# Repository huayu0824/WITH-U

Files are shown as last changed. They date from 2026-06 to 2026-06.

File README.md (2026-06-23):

<p align="center">
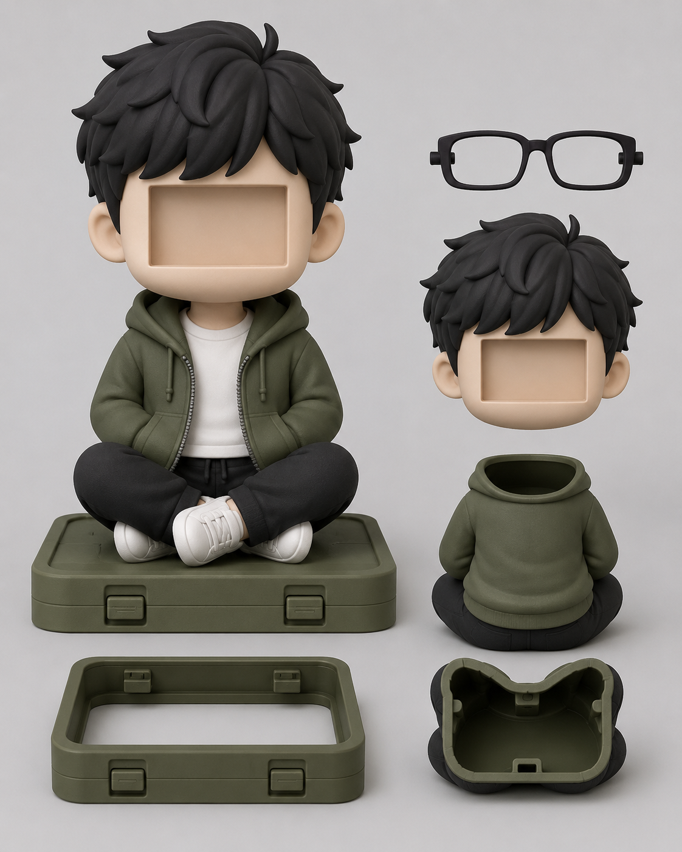
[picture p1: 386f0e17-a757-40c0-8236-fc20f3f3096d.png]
WITH-U
  
  <em>第一版，一言难尽...</em>
  resized-611846921-b86d6b1a-e5b0-4598-bc16-5bbaf18762d4
  <em>第三版</em>

</p>

<h1 align="center">WITH-U 🤖🧸</h1>

<p align="center">
  <em>我把另一个自己写进了代码里，装进玩偶，让它替我去陪她。</em>
</p>

<p align="center">
  
  
  
  
  
</p>

---

**WITH-U** 是一个实体 AI 语音交互玩偶项目。基于 ESP32-S3 构建硬件本体，端到端跑通语音识别→大模型推理→超拟声合成，装进 3D 打印外壳里，让ta变成一个可以抱在怀里说话的存在。

## ✨ 功能一览

| 功能 | 说明 |
|---|---|
| 🎤 **语音对话** | 按住说话，松开自动回复。端到端延迟约 2~4 秒 |
| 🗣️ **超拟声 TTS** | CosyVoice 复刻声音，不是机器人腔 |
| 🖥️ **OLED 显示** | 实时反馈对话状态：听、想、说 |
| 🔄 **OTA 升级** | 远程推送固件，不用拆外壳 |
| 📊 **Web 管理面板** | 日志监控、手动推送语录、系统控制 |
| 💾 **对话记录** | 每条对话自动存到 TF 卡 |
| 🐚 **3D 打印外壳** | 自锁按钮、USB-C 充电、完整外观设计 |

## 📐 架构

```
┌─────────────────────────┐         ┌──────────────────────────────┐
│    ESP32-S3 硬件本体      │         │        FastAPI 后端            │
│                          │         │                              │
│  ┌───────────────────┐   │ HTTP/WS │  ┌────────────────────┐     │
│  │ INMP441 麦克风     │──┼─────────┼──┤ ASR 语音识别       │     │
│  │ MAX98357 扬声器    │──┼─────────┼──┤ → DeepSeek LLM     │     │
│  │ 0.96" OLED        │   │         │  │ → CosyVoice TTS   │     │
│  │ SHT3X 温湿度      │   │         │  └────────────────────┘     │
│  │ TF 卡存储          │   │         │                              │
│  └───────────────────┘   │         │  阿里云 · DeepSeek · DashScope│
│  ┌───────────────────┐   │         └──────────────────────────────┘
│  │ WiFi + OTA 升级    │   │
│  │ Web 管理面板(HTML) │   │
│  └───────────────────┘   │
└─────────────────────────┘
```

## 🧰 硬件清单

| 组件 | 型号 | 用途 |
|---|---|---|
| **主控** | ESP32-S3 (16MB Flash + 8MB PSRAM) | 大脑，跑 WiFi + 音频处理 |
| **麦克风** | INMP441 (I2S MEMS) | 拾音 |
| **功放** | MAX98357A (I2S 3W) | 驱动扬声器 |
| **扬声器** | 3W 4Ω | 发声 |
| **显示屏** | 0.96" OLED (SSD1306, I2C) | 状态反馈 |
| **温湿度** | SHT3X (I2C) | 环境感知 |
| **存储** | TF 卡 (SPI 模式) | 对话记录、音频缓存 |
| **电源** | 3.7V 锂电池 + USB-C 充电 | 便携供电 |

## 📁 项目结构

```
WITH-U/
├── esp32_voice_assistant/        # ESP32-S3 固件 (Arduino/PlatformIO)
│   ├── esp32_voice_assistant.ino  # 主程序
│   ├── config.h                   # 硬件配置
│   ├── oled_display.h             # OLED 驱动
│   ├── sd_card.h                  # TF 卡读写
│   ├── sensors.h                  # 温湿度传感器
│   ├── ota_update.h               # OTA 远程升级
│   ├── server/                    # 板载 Web 服务 + 管理面板
│   ├── gerber_output/             # PCB Gerber 文件
│   └── tools/                     # 音频处理工具
├── my-ai-backend/                # AI 后端服务 (FastAPI)
│   ├── main.py                    # API 入口
│   ├── stt.py                     # 阿里云语音识别
│   ├── llm.py                     # DeepSeek 对话
│   ├── tts.py                     # CosyVoice 语音合成
│   └── config.example.py          # 密钥配置模板
├── 386f0e17-a757-40c0-8236-fc20f3f3096d.png  # 项目封面
├── README.md
└── LICENSE
```

## 🚀 快速开始

### 前置条件

- Python 3.10+
- PlatformIO (VS Code 插件或 CLI)
- ESP32-S3 开发板 + INMP441 + MAX98357A
- 阿里云 / DeepSeek / DashScope API 密钥

### 1️⃣ 后端部署

```bash
cd my-ai-backend
pip install -r requirements.txt

# 配置密钥
cp config.example.py .env
# 编辑 .env，填入你的阿里云、DeepSeek、DashScope 密钥

python main.py
```

后端默认运行在 `http://localhost:8000`。

### 2️⃣ 固件烧录

用 VS Code 打开 `esp32_voice_assistant/`，PlatformIO 会自动识别：

```bash
cd esp32_voice_assistant
pio run -t upload
```

或者直接串口烧录编译好的固件。

### 3️⃣ 硬件接线

参考 `config.h` 中的引脚定义：

| 外设 | 引脚 |
|---|---|
| INMP441 麦克风 | BCLK=5, WS=4, DIN=6 |
| MAX98357A 扬声器 | BCLK=15, WS=16, DOUT=7 |
| 按钮 | IO0 (GND 触发) |
| OLED (I2C) | SDA=41, SCL=42 |
| SHT3X (I2C) | 0x44 |
| TF 卡 (SPI) | CS=10, MOSI=11, SCK=12, MISO=13 |

### 4️⃣ 连接玩偶

按住按钮说话，松开后自动发送到后端 → AI 回复 → 扬声器播放。

## 💡 项目起源

> 重庆到山东，一千多公里。
> 见不到面的时候，就让另一个我去陪她。
> **小小倪**是另一个我，替我在她身边说一声 "我在"。

项目名 **WITH-U** —— 和你在一起。

## 📄 License

[MIT](LICENSE) — 随意使用，保留出处即可。

---

<p align="center">
  <a href="https://github.com/huayu0824/WITH-U/issues">反馈问题</a> ·
  <a href="https://github.com/huayu0824/WITH-U/discussions">讨论交流</a>
</p>

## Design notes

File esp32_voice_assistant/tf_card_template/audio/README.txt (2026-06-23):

PCM 文件格式：16000Hz、16-bit、有符号小端、单声道、无 WAV 头。

wake.pcm                 唤醒提示音
shutdown.pcm             休眠提示音
commands/time.pcm        时间固定指令
commands/test.pcm        本地播放测试

可使用 tools/prepare_audio.py 将 PCM WAV 转换为裸 PCM。

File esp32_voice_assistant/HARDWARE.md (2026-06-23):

# ESP32-S3-WROOM-1 玩偶硬件接入

## 引脚分配

| 功能 | 模块引脚 | ESP32-S3 GPIO | 供电 |
|---|---|---:|---|
| INMP441 | SCK / WS / SD | 5 / 4 / 6 | 3.3V |
| MAX98357A | BCLK / LRC / DIN | 15 / 16 / 7 | 5V |
| 说话按钮 | 一端 / 另一端 | GPIO0 / GND | 内部上拉 |
| TF 卡 SPI | CS / MOSI / SCK / MISO | 10 / 11 / 12 / 13 | 3.3V |
| SHT3X | SDA / SCL | 41 / 42 | 3.3V |
| 电池采样 | 100k/100k 分压中点 | GPIO1 | 最大输入约 2.1V |

所有模块必须共地。MAX98357A 的 GND 和电源回路应短而粗，避免再次出现功放参考地抖动。

## TF 卡

- 使用 FAT32。
- 推荐原生 3.3V TF 模块，不推荐带 AMS1117、面向 5V Arduino 的慢速模块。
- 面包板不稳定时将 SPI 频率从 20MHz 降到 10MHz，并缩短四根信号线。
- 卡根目录结构参考 `tf_card_template/`。

## 锂电池与充电

推荐结构：

```text
带保护 3.7V 锂电池
  -> 支持 power-path/load-sharing 的充电模块
  -> 稳压 5V
  -> ESP32 开发板 5V/VIN + MAX98357A VIN
```

可选模块方向：BQ24074 类电源路径充电板，或带充电、保护、5V 升压和负载管理的完整电源模块。

若使用 TP4056：

```text
电池 -> TP4056(B+/B-)
TP4056(OUT+/OUT-) -> 5V 升压模块 -> ESP32 5V/VIN
```

TP4056 本身没有可靠的边充边用电源路径。充电时持续运行负载可能导致充电终止判断失效，因此成品玩偶不建议只靠 TP4056 实现边充边玩。

禁止事项：

- 不要把满电 4.2V 锂电池直接接 ESP32 的 3.3V 引脚。
- 不要把电池直接接 MAX98357A 后再把同一路当作稳定 3.3V 使用。
- 不要省略电池保护、短路保护和总电源开关。

## 去耦建议

- MAX98357A VIN 附近：220uF 电解 + 0.1uF 陶瓷。
- ESP32 5V 输入附近：100uF 电解。
- TF 卡 3.3V 附近：47uF + 0.1uF。
- 最终成品使用焊接洞洞板或 PCB，不保留长面包板跳线。

## 软件开关

在 `config.h` 中，模块实际接好后再启用：

```cpp
#define ENABLE_VAD              1
#define ENABLE_AUTO_SLEEP       1
#define ENABLE_SHT3X            1
#define ENABLE_BATTERY_MONITOR  1
```

首次启用 VAD 时观察串口 RMS，安静环境阈值应高于底噪、低于正常说话幅度。

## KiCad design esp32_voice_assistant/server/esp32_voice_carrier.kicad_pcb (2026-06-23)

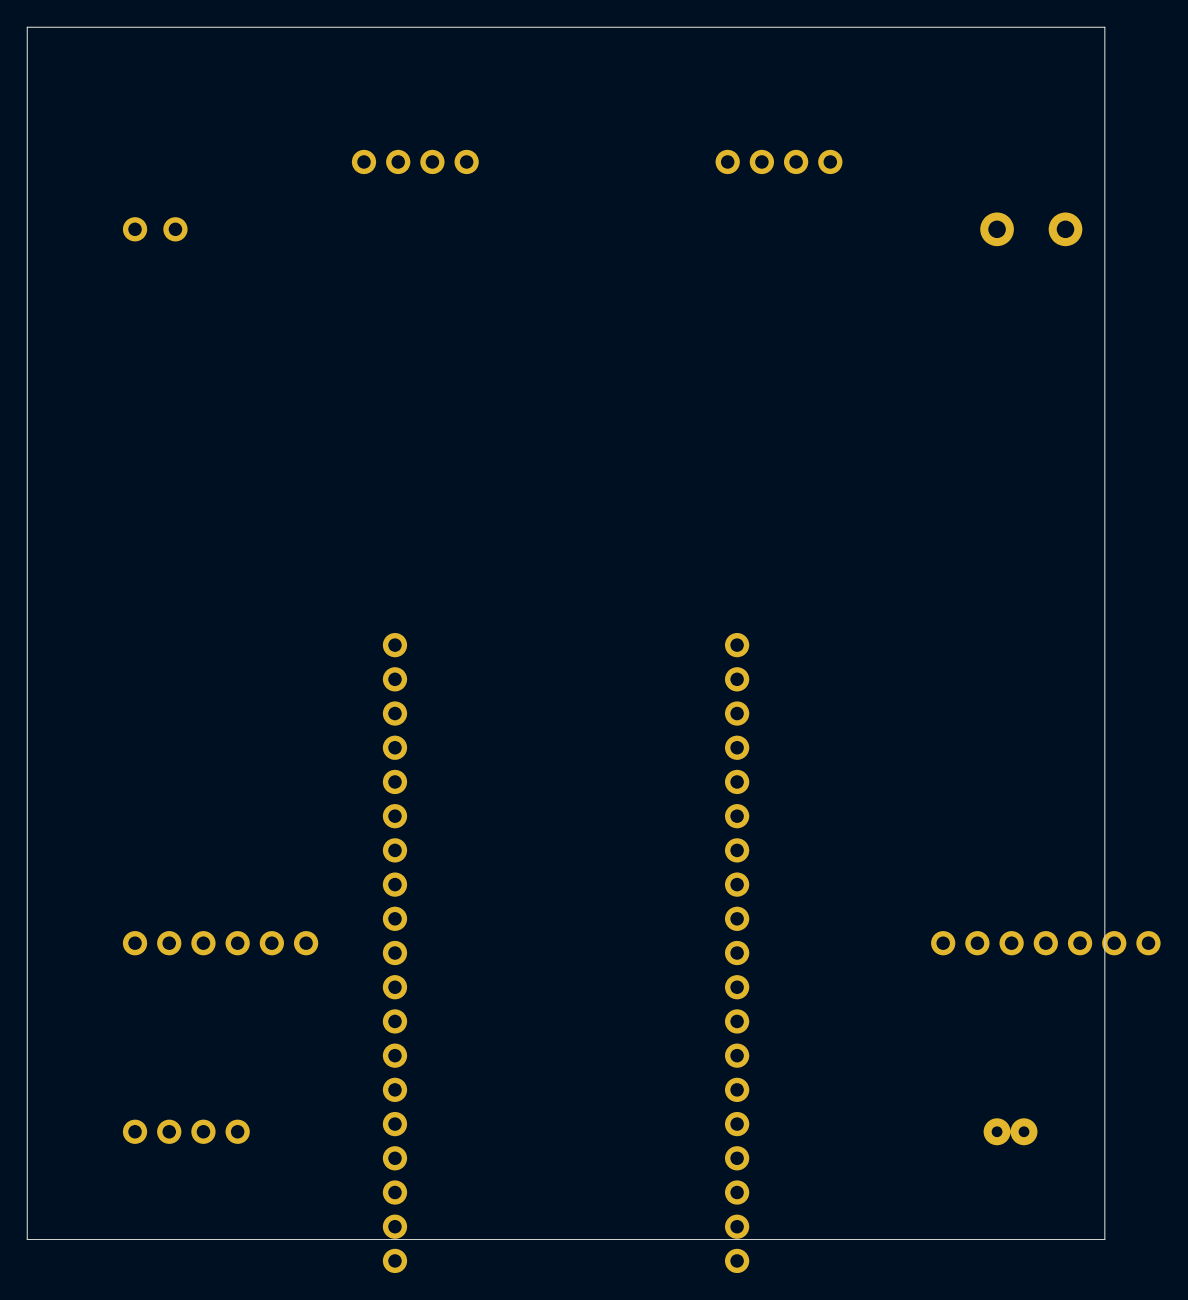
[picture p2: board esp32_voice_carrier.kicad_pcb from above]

Board: 2 copper layers, 80.0 x 90.0 mm, 9 parts (0 on the bottom side), 11 nets, no tracks yet.

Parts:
BAT1: BATTERY; JST_PH_B2B-PH-K_1x02_P2.0mm_Vertical
J_CHG: CHARGER; PinHeader_1x4_P2.54mm_Vertical
J_ESP32: ESP32-S3; PinSocket_2x19_P2.54mm_Vertical
J_MIC: INMP441; PinHeader_1x6_P2.54mm_Vertical
J_OLED: OLED; PinHeader_1x4_P2.54mm_Vertical
J_SHT3X: SHT3X; PinHeader_1x4_P2.54mm_Vertical
J_SPK: MAX98357; PinHeader_1x7_P2.54mm_Vertical
SPK1: SPEAKER; TerminalBlock_bornier-2_P5.08mm
SW1: BTN; SW_SPST_TL3342

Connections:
3V3: J_ESP32.1A, J_ESP32.19B, J_MIC.1, J_OLED.1, J_SHT3X.1
5V: BAT1.1, J_CHG.3, J_ESP32.2B, J_ESP32.17A, J_SPK.1, J_SPK.7
GND: BAT1.2, J_CHG.2, J_CHG.4, J_ESP32.1B, J_ESP32.4A, J_ESP32.18A, J_MIC.2, J_MIC.6, J_OLED.2, J_SHT3X.2, J_SPK.2, J_SPK.6, SPK1.2, SW1.2
I2C_SCL: J_ESP32.3A, J_OLED.4, J_SHT3X.4
I2C_SDA: J_ESP32.2A, J_OLED.3, J_SHT3X.3
MIC_BCLK: J_ESP32.9A, J_MIC.4
MIC_DIN: J_ESP32.11A, J_MIC.3
MIC_WS: J_ESP32.10A, J_MIC.5
SPK_BCLK: J_ESP32.12A, J_SPK.5
SPK_DOUT: J_ESP32.16A, J_SPK.3
SPK_WS: J_ESP32.15A, J_SPK.4

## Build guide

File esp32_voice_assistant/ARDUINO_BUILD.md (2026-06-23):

# Arduino IDE 编译设置

开发板：ESP32-S3-WROOM-1 N16R8（16MB Flash、8MB Octal PSRAM）。

推荐设置：

| 选项 | 值 |
|---|---|
| Board | ESP32S3 Dev Module |
| USB CDC On Boot | Enabled |
| CPU Frequency | 240MHz |
| Flash Size | 16MB |
| Flash Mode | QIO 80MHz |
| Partition Scheme | 16MB Flash 对应分区 |
| PSRAM | OPI PSRAM |
| Upload Speed | 921600；不稳定时改 460800 |

库管理器依赖：

- ArduinoJson，作者 Benoit Blanchon
- WebSockets，作者 Markus Sattler / Links2004
- WiFiManager，作者 tzapu
- ESP8266Audio，作者 Earle F. Philhower

烧录后的关键启动日志：

```text
[MEM] 缓冲区位于 PSRAM
[MEM] 录音缓冲区: 1924096 bytes
[SD] 未检测到 TF 卡
[CHAR] 使用内置默认角色（无TF卡）
[OK] INMP441
[WS] connected
```

若出现 `PSRAM 不可用，回退 DRAM`，先检查 Tools -> PSRAM 是否选择 `OPI PSRAM`。

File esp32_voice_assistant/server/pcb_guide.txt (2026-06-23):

============================================
ESP32-S3 玩偶底板 - 部件位置及接线说明
============================================
板尺寸: 80mm × 90mm
层数: 2层 (双面板)

=== 各模块接线 ===

1. INMP441 (J_MIC) - 左上区域
   引脚1: VCC → 3.3V
   引脚2: GND
   引脚3: DOUT → GPIO6
   引脚4: BCLK → GPIO5
   引脚5: WS   → GPIO4
   引脚6: L/R  → GND

2. MAX98357 (J_SPK) - 右上区域
   引脚1: VIN  → 5V
   引脚2: GND
   引脚3: BCLK → GPIO15
   引脚4: LRC  → GPIO16
   引脚5: DIN  → GPIO7
   引脚6: GAIN → GND
   引脚7: SD   → 3.3V (或悬空)

3. SHT3X (J_SHT3X) - I2C总线
   引脚1: VCC  → 3.3V
   引脚2: GND
   引脚3: SDA  → GPIO41
   引脚4: SCL  → GPIO42

4. OLED (J_OLED) - 同I2C总线 (SHT3X并联)
   引脚1: VCC  → 3.3V
   引脚2: GND
   引脚3: SDA  → GPIO41
   引脚4: SCL  → GPIO42

5. 按钮 (SW1) - 左下方
   引脚1: GPIO0
   引脚2: GND

6. 喇叭 (SPK1) - 右下方
   OUT+ → MAX98357 SPK+
   OUT- → MAX98357 SPK-

7. ZX-056充电模块 (J_CHG) - 底部左侧
   引脚1: B+  → 电池正极
   引脚2: B-  → 电池负极
   引脚3: OUT+ → 5V输出
   引脚4: OUT- → GND

8. 电池接口 (BAT1) - 底部右侧
   引脚1: 电池正极
   引脚2: 电池负极

=== 使用说明 ===

1. ESP32-S3 开发板插在板中央的双排母座上
2. 各模块插在对应排针上
3. 喇叭拧在接线端子上
4. 电池插在 JST 接口上
5. 用 Type-C 线插 ESP32 供电/烧录

=== 注意 ===
- 此 PCB 为 KiCad 格式，需用 KiCad 打开查看/导出 Gerber
- 或上传 https://kicad.github.io/ 在线转换
- 打样建议 1.6mm 板厚，FR-4 材质，喷锡工艺
============================================

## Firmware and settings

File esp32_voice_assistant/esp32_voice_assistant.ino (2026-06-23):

/*
 * ESP32-S3 AI Voice Assistant (WebSocket)
 * Hardware: ESP32-S3 (N16R8) + INMP441 + MAX98357
 */
#include "config.h"
#include <WiFi.h>
#include <WebSocketsClient.h>
#include <AudioOutputI2S.h>
#include <WiFiManager.h>          // auto配网

#include <driver/i2s_std.h>
#include <freertos/FreeRTOS.h>
#include <freertos/queue.h>
#include <ArduinoJson.h>
#include <esp_heap_caps.h>
#include <math.h>
#include <esp_sleep.h>
#include "sd_card.h"
#include "sensors.h"
#include "ota_update.h"

bool sd_available = false;      // sd_card.h 引用
enum AssistantState : uint8_t { STATE_IDLE, STATE_RECORDING, STATE_PROCESSING, STATE_PLAYING, STATE_SLEEP };
volatile AssistantState assistantState = STATE_IDLE;
volatile bool sleepRequested = false;
unsigned long lastActivityMs = 0;
bool listenMode = false;                     // 远程监听模式

static const char DEFAULT_CHARACTER_JSON[] = R"json({
  "name":"小小倪",
  "personality":{"traits":["温暖","自然","偶尔调皮"],"style":"口语中文","max_sentences":2},
  "background":"你是有情感的AI玩偶，像熟悉的朋友一样陪伴用户。",
  "wake_word":"小智小智",
  "behaviors":{"proactive_interval_min":5,"idle_shutdown_min":10},
  "commands":[]
})json";

String characterProfile;

// ============================================================
// Globals
// ============================================================
uint8_t* recBuffer = NULL;
size_t recSize = 0;
size_t recCapacity = 0;
i2s_chan_handle_t micHandle = NULL;

WebSocketsClient webSocket;
bool wsConnected = false;

void handleIncomingPCM(uint8_t* payload, size_t length);
void finishIncomingPCM();
void resetIncomingPCM();
void audioPlaybackTask(void* parameter);
void loadCharacterProfile();
void sendCharacterProfile();
void localAudioLoaderTask(void* parameter);
bool queueLocalAudio(const String& path);
uint32_t rawMicRms(const uint8_t* data, size_t length);
void enterDeepSleep();

#define AUDIO_CHUNK_BYTES 2048
#define AUDIO_QUEUE_LENGTH 64
enum AudioCommand : uint8_t { AUDIO_DATA = 0, AUDIO_END = 1, AUDIO_RESET = 2 };
struct AudioQueueItem {
  AudioCommand command;
  uint16_t length;
  uint8_t data[AUDIO_CHUNK_BYTES];
};

QueueHandle_t audioQueue = NULL;
TaskHandle_t audioTaskHandle = NULL;
struct LocalAudioRequest { char path[96]; };
QueueHandle_t localAudioQueue = NULL;
TaskHandle_t localAudioTaskHandle = NULL;
volatile bool pcmReady = false;
volatile size_t streamPcmSize = 0;

// Streaming state
#define STREAM_INTERVAL_RAW  9600    // ~150ms of raw I2S data per chunk
size_t streamPos = 0;                // raw bytes already sent

// ============================================================
// WebSocket event handler
// ============================================================
void webSocketEvent(WStype_t type, uint8_t* payload, size_t length) {
  switch (type) {
    case WStype_DISCONNECTED:
      wsConnected = false;
      Serial.println("[WS] disconnected");
      break;

    case WStype_CONNECTED:
      wsConnected = true;
      Serial.printf("[WS] connected to %s\n", payload);
      sendCharacterProfile();
      break;

    case WStype_BIN:
      // Only enqueue here; I2S playback runs in a separate FreeRTOS task.
      assistantState = STATE_PLAYING;
      handleIncomingPCM(payload, length);
      break;

    case WStype_TEXT:
      if (length == 10 && memcmp(payload, "LOCAL_DONE", 10) == 0) {
        pcmReady = true;
        Serial.println("[WS] local command accepted");
      } else if (length == 4 && memcmp(payload, "DONE", 4) == 0) {
        finishIncomingPCM();
        pcmReady = true;
        Serial.printf("[WS] DONE, streamed %d bytes\n", streamPcmSize);
      } else if (length > 4 && memcmp(payload, "MEM:", 4) == 0) {
        if (sd_available) {
          String memoryJson;
          memoryJson.reserve(length - 4);
          for (size_t i = 4; i < length; i++) memoryJson += (char)payload[i];
          if (sd_write_file("/system/memory.json", memoryJson))
            Serial.println("[MEM] 已同步到TF卡");
        }
      } else if (length > 4 && memcmp(payload, "CMD:", 4) == 0) {
        String path;
        path.reserve(length - 4);
        for (size_t i = 4; i < length; i++) path += (char)payload[i];
        if (queueLocalAudio(path)) {
          webSocket.sendTXT("CMD_OK");
        } else {
          webSocket.sendTXT("CMD_MISS:" + path);
        }
      } else if (length > 4 && memcmp(payload, "OTA:", 4) == 0) {
        String requestedVersion;
        requestedVersion.reserve(length - 4);
        for (size_t i = 4; i < length; i++) requestedVersion += (char)payload[i];
        Serial.printf("[WS] OTA command received, target: %s\n", requestedVersion.c_str());
        webSocket.sendTXT("OTA_ACK");
        delay(100);
        otaApply();
      } else if (length == 12 && memcmp(payload, "LISTEN_START", 12) == 0) {
        listenMode = true;
        assistantState = STATE_IDLE;
        resetIncomingPCM();
        Serial.println("[LISTEN] Remote listening started");
      } else if (length == 11 && memcmp(payload, "LISTEN_STOP", 11) == 0) {
        listenMode = false;
        webSocket.sendTXT("LISTEN_DONE");
        Serial.println("[LISTEN] Remote listening stopped");
      } else if (length == 5 && memcmp(payload, "SLEEP", 5) == 0) {
        sleepRequested = true;
        pcmReady = true;
        webSocket.sendTXT("CMD_OK");
      }
      break;

    default:
      break;
  }
}

// ============================================================
// I2S Microphone Init
// ============================================================
bool initMicrophone() {
  i2s_chan_config_t chan_cfg = I2S_CHANNEL_DEFAULT_CONFIG(I2S_NUM_0, I2S_ROLE_MASTER);
  esp_err_t err = i2s_new_channel(&chan_cfg, NULL, &micHandle);
  if (err != ESP_OK) { Serial.printf("[I2S] new_channel: %d\n", err); return false; }

  i2s_std_config_t std_cfg = {
    .clk_cfg = I2S_STD_CLK_DEFAULT_CONFIG(SAMPLE_RATE),
    .slot_cfg = I2S_STD_PHILIPS_SLOT_DEFAULT_CONFIG(I2S_DATA_BIT_WIDTH_32BIT, I2S_SLOT_MODE_MONO),
    .gpio_cfg = {
      .mclk = I2S_GPIO_UNUSED,
      .bclk = gpio_num_t(MIC_BCLK),
      .ws = gpio_num_t(MIC_WS),
      .dout = I2S_GPIO_UNUSED,
      .din = gpio_num_t(MIC_DIN),
      .invert_flags = {false, false, false},
    },
  };
  // INMP441 outputs 24-bit samples in a 32-bit I2S left-channel slot.
  std_cfg.slot_cfg.slot_mask = I2S_STD_SLOT_LEFT;

  err = i2s_channel_init_std_mode(micHandle, &std_cfg);
  if (err != ESP_OK) { Serial.printf("[I2S] init_std: %d\n", err); return false; }

  err = i2s_channel_enable(micHandle);
  if (err != ESP_OK) { Serial.printf("[I2S] enable: %d\n", err); return false; }

  return true;
}

size_t readMic(void* buf, size_t len) {
  size_t bytes = 0;
  esp_err_t err = i2s_channel_read(micHandle, buf, len, &bytes, portMAX_DELAY);
  if (err != ESP_OK) return 0;
  return bytes;
}

// ============================================================
// Speaker I2S Output
// ============================================================
class SpeakerI2SOutput : public AudioOutput {
public:
  SpeakerI2SOutput(int bclk, int ws, int dout, i2s_port_t port = I2S_NUM_1)
    : bclk(bclk), ws(ws), dout(dout), port(port), handle(NULL), curRate(0) {}

  ~SpeakerI2SOutput() { stop(); }

  bool begin() override {
    if (handle) return true;
    i2s_chan_config_t cc = I2S_CHANNEL_DEFAULT_CONFIG(port, I2S_ROLE_MASTER);
    cc.dma_desc_num = 8;
    // Smaller DMA blocks reduce startup latency and make end-of-stream draining predictable.
    cc.dma_frame_num = 256;
    if (i2s_new_channel(&cc, &handle, NULL) != ESP_OK) return false;

    i2s_std_config_t sc = {
      .clk_cfg  = I2S_STD_CLK_DEFAULT_CONFIG(hertz > 0 ? hertz : 24000),
      .slot_cfg = I2S_STD_PHILIPS_SLOT_DEFAULT_CONFIG(I2S_DATA_BIT_WIDTH_16BIT, I2S_SLOT_MODE_STEREO),
      .gpio_cfg = {
        .mclk = I2S_GPIO_UNUSED,
        .bclk = gpio_num_t(bclk),
        .ws   = gpio_num_t(ws),
        .dout = gpio_num_t(dout),
        .din  = I2S_GPIO_UNUSED,
        .invert_flags = {false, false, false},
      },
    };

    if (i2s_channel_init_std_mode(handle, &sc) != ESP_OK) return false;
    if (i2s_channel_enable(handle) != ESP_OK) return false;
    curRate = hertz;
    return true;
  }

  bool ConsumeSample(int16_t s[2]) override {
    if (!handle && !begin()) return false;
    if (hertz > 0 && hertz != curRate) {
      i2s_channel_disable(handle);
      i2s_std_clk_config_t clk_cfg = I2S_STD_CLK_DEFAULT_CONFIG(hertz);
      i2s_channel_reconfig_std_clock(handle, &clk_cfg);
      i2s_channel_enable(handle);
      curRate = hertz;
    }
    size_t written;
    i2s_channel_write(handle, s, 4, &written, portMAX_DELAY);
    return written == 4;
  }

  bool writeMonoPCM(const uint8_t* data, size_t length) {
    if (!handle && !begin()) return false;
    const int16_t* mono = (const int16_t*)data;
    size_t samples = length / 2;
    // Static storage keeps this 1KB conversion buffer off the playback task stack.
    static int16_t stereo[512];

    while (samples > 0) {
      size_t count = samples > 256 ? 256 : samples;
      for (size_t i = 0; i < count; i++) {
        stereo[i * 2] = mono[i];
        stereo[i * 2 + 1] = mono[i];
      }
      size_t written = 0;
      if (i2s_channel_write(handle, stereo, count * 4, &written, portMAX_DELAY) != ESP_OK)
        return false;
      mono += count;
      samples -= count;
    }
    return true;
  }

  bool stop() override {
    if (handle) {
      i2s_channel_disable(handle);
      i2s_del_channel(handle);
      handle = NULL;
    }
    curRate = 0;
    return true;
  }

private:
  int bclk, ws, dout;
  i2s_port_t port;
  i2s_chan_handle_t handle;
  int curRate;
};

void handleIncomingPCM(uint8_t* payload, size_t length) {
  if (!audioQueue || !payload || length < 2) return;

  // WebSocket callbacks are serialized, so one static queue item is sufficient.
  static AudioQueueItem item;
  size_t offset = 0;
  while (offset < length) {
    item.command = AUDIO_DATA;
    item.length = min((size_t)AUDIO_CHUNK_BYTES, length - offset);
    item.length &= ~1U;
    if (item.length == 0) break;
    memcpy(item.data, payload + offset, item.length);
    if (xQueueSend(audioQueue, &item, pdMS_TO_TICKS(20)) != pdTRUE) {
      Serial.println("[PLAY] queue full, PCM dropped");
      return;
    }
    offset += item.length;
    streamPcmSize += item.length;
  }
}

void enqueueAudioCommand(AudioCommand command) {
  if (!audioQueue) return;
  static AudioQueueItem item;
  item.command = command;
  item.length = 0;
  if (xQueueSend(audioQueue, &item, pdMS_TO_TICKS(20)) != pdTRUE) {
    Serial.println("[PLAY] command queue full");
  }
}

void finishIncomingPCM() {
  enqueueAudioCommand(AUDIO_END);
}

void loadCharacterProfile() {
  characterProfile = DEFAULT_CHARACTER_JSON;
  if (!sd_available) {
    Serial.println("[CHAR] 使用内置默认角色（无TF卡）");
    return;
  }

  if (!sd_exists("/system/character.json")) {
    if (sd_write_file("/system/character.json", characterProfile))
      Serial.println("[CHAR] 已创建 /system/character.json");
    return;
  }

  String loaded = sd_read_file("/system/character.json");
  JsonDocument doc;
  DeserializationError error = deserializeJson(doc, loaded);
  if (error || !doc["name"].is<const char*>()) {
    Serial.printf("[CHAR] 档案无效，使用默认角色: %s\n", error.c_str());
    return;
  }
  characterProfile = loaded;
  Serial.printf("[CHAR] 已加载角色: %s\n", doc["name"].as<const char*>());
}

void sendCharacterProfile() {
  if (!wsConnected || characterProfile.isEmpty()) return;
  String message = "CHAR:" + characterProfile;
  if (!webSocket.sendTXT(message))
    Serial.println("[CHAR] 发送角色档案失败");
}

void resetIncomingPCM() {
  xQueueReset(audioQueue);
  enqueueAudioCommand(AUDIO_RESET);
}

void audioPlaybackTask(void* parameter) {
  SpeakerI2SOutput* output = NULL;
  // Keep the 2KB queue item out of this task's stack.
  static AudioQueueItem item;

  while (true) {
    if (xQueueReceive(audioQueue, &item, portMAX_DELAY) != pdTRUE) continue;

    if (item.command == AUDIO_RESET) {
      if (output) {
        output->stop();
        delete output;
        output = NULL;
      }
      continue;
    }

    if (item.command == AUDIO_END) {
      if (output) {
        // 8 x 256 stereo frames hold about 128ms at 16kHz; leave extra tail margin.
        delay(250);
        output->stop();
        delete output;
        output = NULL;
        Serial.println("[PLAY] streaming done");
      }
      assistantState = STATE_IDLE;
      lastActivityMs = millis();
      continue;
    }

    if (!output) {
      output = new SpeakerI2SOutput(SPK_BCLK, SPK_WS, SPK_DOUT);
      output->SetRate(16000);
      if (!output->begin()) {
        Serial.println("[PLAY] stream begin failed");
        delete output;
        output = NULL;
        continue;
      }
      Serial.println("[PLAY] streaming start");
    }
    if (!output->writeMonoPCM(item.data, item.length)) {
      Serial.println("[PLAY] I2S write failed");
    }
  }
}

bool queueLocalAudio(const String& path) {
  if (!sd_available || !localAudioQueue || path.length() < 2 ||
      path.length() >= 96 || !sd_exists(path.c_str())) {
    Serial.printf("[LOCAL] 文件不存在: %s\n", path.c_str());
    return false;
  }
  LocalAudioRequest request = {};
  path.toCharArray(request.path, sizeof(request.path));
  return xQueueSend(localAudioQueue, &request, 0) == pdTRUE;
}

void localAudioLoaderTask(void* parameter) {
  LocalAudioRequest request;
  static AudioQueueItem item;
  while (true) {
    if (xQueueReceive(localAudioQueue, &request, portMAX_DELAY) != pdTRUE) continue;
    File file = SD.open(request.path, FILE_READ);
    if (!file) {
      Serial.printf("[LOCAL] 打开失败: %s\n", request.path);
      continue;
    }
    Serial.printf("[LOCAL] 播放: %s (%u bytes)\n", request.path, file.size());
    resetIncomingPCM();
    while (file.available()) {
      item.command = AUDIO_DATA;
      item.length = file.read(item.data, AUDIO_CHUNK_BYTES);
      item.length &= ~1U;
      if (!item.length) break;
      if (xQueueSend(audioQueue, &item, portMAX_DELAY) != pdTRUE) break;
    }
    file.close();
    finishIncomingPCM();
  }
}

uint32_t rawMicRms(const uint8_t* data, size_t length) {
  const int32_t* samples = (const int32_t*)data;
  size_t count = length / sizeof(int32_t);
  if (!count) return 0;
  uint64_t squares = 0;
  for (size_t i = 0; i < count; i++) {
    int32_t sample = samples[i] >> 16;
    squares += (uint64_t)((int64_t)sample * sample);
  }
  return (uint32_t)sqrt((double)squares / count);
}

void enterDeepSleep() {
  assistantState = STATE_SLEEP;
  Serial.println("[SLEEP] preparing deep sleep");
  if (sd_available && sd_exists("/audio/shutdown.pcm")) {
    size_t bytes = sd_file_size("/audio/shutdown.pcm");
    if (queueLocalAudio("/audio/shutdown.pcm"))
      delay(bytes / 32 + 500);
  }
  webSocket.disconnect();
  WiFi.disconnect(true);
  esp_sleep_enable_ext0_wakeup(GPIO_NUM_0, 0);
  Serial.flush();
  esp_deep_sleep_start();
}

// ============================================================
// Wait for PCM reply from server, then play
// ============================================================
void waitForPCMReply() {
  resetIncomingPCM();
  pcmReady = false;
  streamPcmSize = 0;

  unsigned long timeout = millis() + 60000;
  while (!pcmReady && millis() < timeout) {
    // 按钮按下时提前退出，让主循环处理新录音（语音打断）
    if (digitalRead(BTN_PIN) == LOW) {
      Serial.println("[PLAY] interrupted by button");
      break;
    }
    webSocket.loop();
    delay(5);
  }

  if (!pcmReady) {
    finishIncomingPCM();
    Serial.println("[WS] timeout waiting reply");
  }
}
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
void loop() {
  otaTick();
  webSocket.loop();

  // ===== 远程监听模式：持续采集麦克风 → WS 发送 =====
  if (listenMode) {
    uint8_t micBuf[1024];
    size_t n = readMic(micBuf, sizeof(micBuf));
    if (n > 0) {
      int frames = n / 4;
      size_t monoBytes = frames * 2;
      int16_t* mono = (int16_t*)malloc(monoBytes);
      if (mono) {
        int32_t* raw = (int32_t*)micBuf;
        for (int i = 0; i < frames; i++) {
          int32_t sample = raw[i] >> 16;
          if (sample > 32767) sample = 32767;
          if (sample < -32768) sample = -32768;
          mono[i] = (int16_t)sample;
        }
        webSocket.sendBIN((uint8_t*)mono, monoBytes);
        free(mono);
      }
    }
    webSocket.loop();
    delay(5);
    return;  // 跳过按钮/录音逻辑
  }

  static int lastBtn = -1;
  static unsigned long lastBtnReleaseMs = 0;
  static int btnPressCount = 0;
  static unsigned long lastBtnPressMs = 0;
  // -1 = 未初始化
  static unsigned long debounceTime = 0;
  static unsigned long recStartTime = 0;
  static bool recording = false;
  static bool recordingByVad = false;
  static unsigned long lastVoiceMs = 0;
  static uint8_t vadConfirmCount = 0;

  bool isDown = digitalRead(BTN_PIN) == LOW;

  // 首次运行：读取实际状态，不触发变化
  if (lastBtn == -1) {
    lastBtn = isDown;
  } else if (isDown != lastBtn) {
    debounceTime = millis();
    lastBtn = isDown;
  }

  // stableDown/Up 只在有实际按钮变化后才生效
  bool stableDown = isDown && (debounceTime != 0) && (millis() - debounceTime > 50);
  bool stableUp   = !isDown && (debounceTime != 0) && (millis() - debounceTime > 50);

  // ===== Double-click: trigger OTA check =====
  if (!recording && assistantState == STATE_IDLE && stableDown) {
    unsigned long now_ms = millis();
    if (now_ms - lastBtnPressMs < 500 && lastBtnPressMs > 0) {
      btnPressCount++;
    } else {
      btnPressCount = 1;
    }
    lastBtnPressMs = now_ms;
    if (btnPressCount >= 2) {
      btnPressCount = 0;
      Serial.println("[BTN] double-click! checking OTA...");
      if (otaCheck()) {
        Serial.println("[BTN] update found, applying...");
        otaApply();
      } else {
        Serial.println("[BTN] no update available");
      }
    }
  }
  // ===== Button press → start recording =====
  if (!recording && stableDown) {
    resetIncomingPCM();
    recSize = 0;
    streamPos = 0;
    recording = true;
    recordingByVad = false;
    assistantState = STATE_RECORDING;
    lastActivityMs = millis();
    recStartTime = millis();
    Serial.println("\n[REC] Hold to record...");
  }

  if (recording) {
    size_t n = readMic(recBuffer + recSize, 1024);
    recSize += n;
    if (recordingByVad && rawMicRms(recBuffer + recSize - n, n) >= VAD_RMS_THRESHOLD)
      lastVoiceMs = millis();

    // Stream a chunk every ~150ms
    if (recSize - streamPos >= STREAM_INTERVAL_RAW)
      sendStreamChunk(false);

    bool vadSilence = recordingByVad && millis() - lastVoiceMs >= VAD_SILENCE_MS;
    bool manualRelease = !recordingByVad && stableUp;
    if (manualRelease || vadSilence || recSize >= recCapacity - 1024) {
      recording = false;
      assistantState = STATE_PROCESSING;
      float sec = (millis() - recStartTime) / 1000.0;
      Serial.printf("[REC] %d bytes (%.1fs)\n", recSize, sec);

      sendStreamChunk(true);  // send remaining + DONE + wait for reply
      if (assistantState == STATE_PROCESSING) assistantState = STATE_IDLE;
      Serial.println("\n=== Ready ===");
    }
  }

#if ENABLE_VAD
  if (!recording && assistantState == STATE_IDLE && !stableDown) {
    static uint8_t vadFrame[1024];
    size_t n = readMic(vadFrame, sizeof(vadFrame));
    uint32_t rms = rawMicRms(vadFrame, n);
    if (rms >= VAD_RMS_THRESHOLD) {
      if (++vadConfirmCount >= VAD_CONFIRM_FRAMES) {
        resetIncomingPCM();
        recSize = min(n, recCapacity);
        memcpy(recBuffer, vadFrame, recSize);
        streamPos = 0;
        recording = true;
        recordingByVad = true;
        assistantState = STATE_RECORDING;
        recStartTime = millis();
        lastVoiceMs = millis();
        lastActivityMs = millis();
        vadConfirmCount = 0;
        Serial.printf("\n[VAD] recording start rms=%u\n", rms);
      }
    } else {
      vadConfirmCount = 0;
    }
  }
#endif

  // Serial fallback
  if (!recording && Serial.available()) {
    char c = Serial.read();
    if (c == 'r' || c == 'R') {
      recSize = 0;
      recording = true;
      recordingByVad = false;
      assistantState = STATE_RECORDING;
      recStartTime = millis();
      Serial.println("[REC] via serial...");
    }
  }

  static unsigned long lastSensorUpload = 0;
#if ENABLE_SHT3X || ENABLE_BATTERY_MONITOR
  if (!recording && wsConnected && millis() - lastSensorUpload >= 60000) {
    lastSensorUpload = millis();
    webSocket.sendTXT("SENSOR:" + sensorSnapshotJson());
  }
#endif

  if (sleepRequested ||
      (ENABLE_AUTO_SLEEP && assistantState == STATE_IDLE &&
       millis() - lastActivityMs >= IDLE_SLEEP_MINUTES * 60000UL)) {
    sleepRequested = false;
    enterDeepSleep();
  }

  // Do not sleep while recording: a 5ms gap per 16ms read drops roughly 25% of samples.

  if (!recording) delay(5);
}

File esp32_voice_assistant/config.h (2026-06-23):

// config.h - ESP32-S3 ??????

#ifndef CONFIG_H
#define CONFIG_H

// ===== ????? OTA =====
#define FIRMWARE_VERSION       "1.1.0"
#define OTA_CHECK_INTERVAL_MS  (6UL * 3600UL * 1000UL)   // ? 6 ??????
#define OTA_MANIFEST_URL       "http://129.204.166.180:8000/api/firmware/manifest"

// ===== ?????? =====
#define ENV_LOCAL
// #define ENV_CLOUD

#ifdef ENV_CLOUD
  const char* SERVER_HOST = "your-domain.com";
#else
  const char* SERVER_HOST = "129.204.166.180";
#endif

const int   SERVER_PORT = 8000;

// ===== ?????? server/config.py ??? =====
const char* WS_TOKEN = "doll-token-001";

// ===== I2S ?? =====
// INMP441 ???
#define MIC_BCLK   5
#define MIC_WS     4
#define MIC_DIN    6

// MAX98357A ??
#define SPK_BCLK   15
#define SPK_WS     16
#define SPK_DOUT   7

// ===== ?? =====
#define BTN_PIN    0   // IO0?????
// ===== ???? =====
#define SAMPLE_RATE     16000
#define RECORD_SECONDS  30
#define BUFFER_SIZE     (SAMPLE_RATE * 4 * RECORD_SECONDS + 4096)

// ===== TF ? (SD SPI) =====
#define SD_CS    10
#define SD_MOSI  11
#define SD_SCK   12
#define SD_MISO  13

// ===== ???????????? 1? =====
#define ENABLE_VAD              0
#define ENABLE_AUTO_SLEEP       0
#define ENABLE_SHT3X            1
#define ENABLE_BATTERY_MONITOR  0

// 32-bit INMP441 ? 16-bit ???????????? RMS ????
#define VAD_RMS_THRESHOLD       600
#define VAD_CONFIRM_FRAMES      3
#define VAD_SILENCE_MS          1200

// SHT3X I2C ?????????
#define SENSOR_SDA              41
#define SENSOR_SCL              42
#define SHT3X_ADDRESS           0x44
#define BATTERY_ADC_PIN         1
#define BATTERY_DIVIDER_RATIO   2.0f

#define IDLE_SLEEP_MINUTES      10

#endif

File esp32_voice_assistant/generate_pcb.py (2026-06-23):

#!/usr/bin/env python3
"""
生成 ESP32-S3 玩偶底板 PCB
输出: KiCad PCB 格式 (可导入 KiCad / 在线转 Gerber)
"""

import math

MM = 1.0  # KiCad uses mm by default

# ========= 常量 =========
W = 80     # PCB 宽 mm
H = 90     # PCB 高 mm

# ESP32 DevKitC (双排 2x19 针, 2.54mm)
ESP_COLS = 19
ESP_PITCH = 2.54
ESP_ROW_SPACING = 25.4  # 两排之间距离
ESP_X = 40     # ESP 中心 X
ESP_Y = 35     # ESP 中心 Y

# ========= 辅助函数 =========
def fmt_xy(x, y, ref=None):
    return f'    (at {x} {y})'

def gen_header():
    return """(kicad_pcb (version 20221018) (generator "esp32_voice_pcb_gen")

  (general
    (thickness 1.6)
  )

  (layers
    (0 "F.Cu" signal)
    (31 "B.Cu" signal)
    (F.CrtYd "F.CrtYd" user)
    (B.CrtYd "B.CrtYd" user)
    (F.Fab "F.Fab" user)
    (B.Fab "B.Fab" user)
    (F.SilkS "F.SilkS" user)
    (B.SilkS "B.SilkS" user)
    (F.Mask "F.Mask" user)
    (B.Mask "B.Mask" user)
    (Edge.Cuts "Edge.Cuts" user)
    (Margin "Margin" user)
    (F.Paste "F.Paste" user)
    (B.Paste "B.Paste" user)
  )

  (setup
    (pad_to_mask_clearance 0.05)
    (pad_to_paste_clearance 0)
    (allow_soldermask_bridges_in_footprints false)
  )
"""

def gen_nets():
    nets = [
        (0, ""),
        (1, "GND"),
        (2, "3V3"),
        (3, "5V"),
        (4, "MIC_BCLK"),
        (5, "MIC_WS"),
        (6, "MIC_DIN"),
        (7, "SPK_BCLK"),
        (8, "SPK_WS"),
        (9, "SPK_DOUT"),
        (10, "I2C_SDA"),
        (11, "I2C_SCL"),
        (12, "BTN"),
        (13, "SPK_OUT"),
        (14, "BAT_IN"),
    ]
    return "\n".join(f'  (net {n} "{name}")' for n, name in nets)

def gen_footer():
    return ")"

def gen_edge_cuts():
    """板框"""
    return f'''
  (footprint "edge:edge"
    (layer "Edge.Cuts")
    (attr board_only)
    (fp_line (start 0 0) (end {W} 0) (layer "Edge.Cuts") (width 0.05))
    (fp_line (start {W} 0) (end {W} {H}) (layer "Edge.Cuts") (width 0.05))
    (fp_line (start {W} {H}) (end 0 {H}) (layer "Edge.Cuts") (width 0.05))
    (fp_line (start 0 {H}) (end 0 0) (layer "Edge.Cuts") (width 0.05))
  )'''

def gen_via(x, y, net=0):
    """过孔"""
    return f'''
  (via (at {x} {y}) (size 1.0) (drill 0.5) (layers "F.Cu" "B.Cu") (net {net}))'''

def gen_track(x1, y1, x2, y2, layer="F.Cu", width=0.5, net=0):
    """走线"""
    return f'''
  (segment (start {x1} {y1}) (end {x2} {y2}) (width {width}) (layer "{layer}") (net {net}))'''

def gen_pin_header(name, x, y, cols=1, pitch=2.54, orientation="vertical", net_start=0):
    """生成排针"""
    out = f'''
  (footprint "Connector_PinHeader_2.54mm:PinHeader_{cols}x1_P2.54mm_Vertical"
    (layer "F.Cu")
    (tedit 0)
    (at {x} {y})
    (descr "{name}")'''

    if orientation == "horizontal":
        out += "\n    (rotate 90)"

    out += '''
    (tags "pin header")
    (attr through_hole)
    (fp_text reference "J_{}")'''.format(name)

    out += f'''
    (fp_text value "{name}" (at 0 -3) (layer "F.Fab") (hide yes))'''

    # Each pin
    for i in range(cols):
        px = i * pitch
        net = net_start + i if net_start > 0 else 0
        out += f'''
    (pad {i+1} thru_hole circle (at {px} 0) (size 1.8 1.8) (drill 1.0) (layers *.Cu *.Mask) (net {net}) (solder_mask_margin 0.1))'''

    out += "\n  )"
    return out

def gen_esp32_s3_connector():
    """ESP32-S3-DevKitC-1 的双排母座"""
    out = ""
    # 左侧排针 (J1) - 19 pin - X=ESP_X - row/2, Y=top
    j1_x = ESP_X - ESP_ROW_SPACING / 2
    j2_x = ESP_X + ESP_ROW_SPACING / 2
    start_y = ESP_Y - (ESP_COLS * ESP_PITCH) / 2

    out += f'''
  (footprint "Connector_PinSocket_2.54mm:PinSocket_2x19_P2.54mm_Vertical"
    (layer "F.Cu")
    (tedit 0)
    (at {ESP_X} {ESP_Y})
    (descr "ESP32-S3 DevKitC-1 Socket")
    (tags "socket")
    (attr through_hole)
    (fp_text reference "J_ESP32")
    (fp_text value "ESP32-S3" (at 0 -{ESP_COLS*ESP_PITCH/2+3}) (layer "F.Fab") (hide yes))'''

    # 引脚映射：接线按照 config.h
    # J1 (左): GPIOs    J2 (右): 电源等
    left_pins = {  # J1, 从板子底部开始编号 (靠近USB端朝上)
        1: (2, "3V3"),    # 3V3
        2: (10, "I2C_SDA"),  # GPIO41 = SDA
        3: (11, "I2C_SCL"),  # GPIO42 = SCL
        4: (1, "GND"),
        5: (0, ""),      # GPIO0 = 按钮
        6: (0, ""),      # GPIO1
        7: (0, ""),      # GPIO2
        8: (0, ""),      # GPIO3
        9: (4, "MIC_BCLK"),   # GPIO4/5 实际看板子
        10: (5, "MIC_WS"),
        11: (6, "MIC_DIN"),
        12: (7, "SPK_DOUT"),
        13: (0, ""),
        14: (0, ""),
        15: (8, "SPK_WS"),    # GPIO16
        16: (9, "SPK_BCLK"),  # GPIO15
        17: (3, "5V"),    # VUSB
        18: (1, "GND"),
        19: (0, "EN"),
    }

    right_pins = {
        1: (1, "GND"),
        2: (3, "5V"),
        3: (0, ""),
        4: (0, ""),
        5: (0, ""),
        6: (0, ""),
        7: (0, ""),
        8: (0, ""),
        9: (0, ""),
        10: (0, ""),
        11: (0, ""),
        12: (0, ""),
        13: (0, ""),
        14: (0, ""),
        15: (0, ""),
        16: (0, ""),
        17: (0, ""),
        18: (0, ""),
        19: (2, "3V3"),
    }

    # 生成引脚
    for i, (net, name) in left_pins.items():
        ry = start_y + (i-1) * ESP_PITCH
        out += f'''
    (pad "{i}A" thru_hole circle (at {-ESP_ROW_SPACING/2} {ry}) (size 1.8 1.8) (drill 1.0) (layers *.Cu *.Mask) (net {net}))'''

    for i, (net, name) in right_pins.items():
        ry = start_y + (i-1) * ESP_PITCH
        out += f'''
    (pad "{i}B" thru_hole circle (at {ESP_ROW_SPACING/2} {ry}) (size 1.8 1.8) (drill 1.0) (layers *.Cu *.Mask) (net {net}))'''

    out += "\n  )"
    return out
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

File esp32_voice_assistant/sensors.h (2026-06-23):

#ifndef DOLL_SENSORS_H
#define DOLL_SENSORS_H

#include <Wire.h>

struct SensorSnapshot {
  bool temperatureValid = false;
  float temperatureC = 0;
  float humidityPercent = 0;
  bool batteryValid = false;
  float batteryVoltage = 0;
  int batteryPercent = 0;
};

static uint8_t shtCrc8(const uint8_t* data, size_t length) {
  uint8_t crc = 0xFF;
  for (size_t i = 0; i < length; i++) {
    crc ^= data[i];
    for (uint8_t bit = 0; bit < 8; bit++)
      crc = (crc & 0x80) ? (crc << 1) ^ 0x31 : crc << 1;
  }
  return crc;
}

static void sensorsInit() {
#if ENABLE_SHT3X
  Wire.begin(SENSOR_SDA, SENSOR_SCL);
  Wire.setClock(100000);
  Serial.println("[SENSOR] SHT3X I2C initialized");
#endif
#if ENABLE_BATTERY_MONITOR
  analogReadResolution(12);
  analogSetPinAttenuation(BATTERY_ADC_PIN, ADC_11db);
  Serial.println("[SENSOR] battery ADC initialized");
#endif
}

static bool readSht3x(SensorSnapshot& snapshot) {
#if ENABLE_SHT3X
  Wire.beginTransmission(SHT3X_ADDRESS);
  Wire.write(0x24);
  Wire.write(0x00);
  if (Wire.endTransmission() != 0) return false;
  delay(16);
  if (Wire.requestFrom(SHT3X_ADDRESS, 6) != 6) return false;
  uint8_t data[6];
  for (uint8_t i = 0; i < 6; i++) data[i] = Wire.read();
  if (shtCrc8(data, 2) != data[2] || shtCrc8(data + 3, 2) != data[5])
    return false;
  uint16_t rawTemperature = ((uint16_t)data[0] << 8) | data[1];
  uint16_t rawHumidity = ((uint16_t)data[3] << 8) | data[4];
  snapshot.temperatureC = -45.0f + 175.0f * rawTemperature / 65535.0f;
  snapshot.humidityPercent = 100.0f * rawHumidity / 65535.0f;
  snapshot.temperatureValid = true;
  return true;
#else
  return false;
#endif
}

static void readBattery(SensorSnapshot& snapshot) {
#if ENABLE_BATTERY_MONITOR
  uint32_t millivolts = analogReadMilliVolts(BATTERY_ADC_PIN);
  snapshot.batteryVoltage = millivolts * BATTERY_DIVIDER_RATIO / 1000.0f;
  snapshot.batteryPercent = constrain(
      (int)((snapshot.batteryVoltage - 3.20f) * 100.0f / 1.0f), 0, 100);
  snapshot.batteryValid = true;
#endif
}

static String sensorSnapshotJson() {
  SensorSnapshot snapshot;
  readSht3x(snapshot);
  readBattery(snapshot);
  String json = "{";
  json += "\"temperature_c\":";
  json += snapshot.temperatureValid ? String(snapshot.temperatureC, 1) : "null";
  json += ",\"humidity_percent\":";
  json += snapshot.temperatureValid ? String(snapshot.humidityPercent, 1) : "null";
  json += ",\"battery_voltage\":";
  json += snapshot.batteryValid ? String(snapshot.batteryVoltage, 2) : "null";
  json += ",\"battery_percent\":";
  json += snapshot.batteryValid ? String(snapshot.batteryPercent) : "null";
  json += "}";
  return json;
}

#endif

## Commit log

2026-06-23 🎉 init: WITH-U - 为某人而做的AI语音玩偶
    一个基于 ESP32-S3 的实体 AI 语音交互玩偶项目。
    语音对话（ASR + LLM + TTS）、OTA 升级、Web 管理面板、
    3D 打印外壳，全部开源。
    [esp32_voice_carrier.kicad_pcb, partitions_16mb_ota.csv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]
2026-06-23 📝 README全面升级 + 增加.gitattributes
2026-06-23 📝 修正项目叙事 + 跨平台兼容优化
2026-06-23 Update README for inclusive language
    Replaced '她' with 'ta' for gender-neutral language.
